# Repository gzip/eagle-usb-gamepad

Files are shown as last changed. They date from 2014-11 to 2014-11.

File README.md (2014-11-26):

# Classic Gamepad USB Adapter

This hardware and software allows you to connect your favorite classic gamepad to use as a joystick on your computer. The design is based on work from [raphnet.net](http://raphnet.net/electronique/electronique_en.php#1) and is completely open. The following configurations are supported:

- Four NES and/or SNES gamepads
- One N64 or Gamecube gamepad
- One Genesis or Atari gamepad

Connector footprints are also available for NES, SNES, and N64 under the [breakouts](./breakouts/) folder.

Gerbers

# Availability

Boards available at [OSH Park](https://www.oshpark.com/shared_projects/oCdHAtTx).

Kits available at [Tindie](https://www.tindie.com/products/gzip/classic-gamepad-usb-adapter/).

Photo of circuit

## License

All hardware and software is derivative of raphnet.net and is therefore GPL. The [breakout boards](./breakouts/) are original works and licensed under [Creative Commons Share Alike](http://creativecommons.org/licenses/by-sa/4.0/).

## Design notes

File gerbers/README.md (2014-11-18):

# Gerber Layers

| Layer Description | Extension |
| ---| ---|
| Bottom Copper | GBL |
| Bottom Solder Mask | GBS |
| Bottom Silk | GBO |
| Top Copper | GTL |
| Top Silk | GTO |
| Top Solder Mask | GTS |
| Outline | GML |
| Holes/Drills | TXT |

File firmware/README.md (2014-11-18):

# Firmware for the Classic Gamepad USB Adapter

The software here is provided by [raphnet.net](http://raphnet.net/electronique/electronique_en.php#1) and has been modified minimally to change the data pin(s), remove any code related to jumper settings, and change the VID/PID as requested by the original author. The following configurations are available here:

- Four NES and/or SNES gamepads
- One N64 or Gamecube gamepad
- One Genesis or Atari gamepad

## License

GPL

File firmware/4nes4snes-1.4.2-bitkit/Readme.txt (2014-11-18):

This is 4nes4snes Readme.txt file. 

Table of contents:

1) What is 4nes4snes?
2) USB Implementation
3) Compilation and installation
4) License
5) About the vendor id/product id pair:
6) Where do I get more information and updates?

1) What is 4nes4snes?
   --------------------
	4nes4snes if a firmware for Atmel ATmega8 and Atmega168* 
	which allows one to connect up to 4 NES and/or SNES 
	controllers to a PC using a single circuit. 

	The device connects to an USB port and appears to the
	PC as standard HID joystick with 4 report Id's. This means
	that it looks like 4 controllers in Windows's 
	control_panel->game_controllers window.

* Other devices from the same family are probably supported, but
not tested.

2) USB Implementation
   ------------------
	4nes4snes uses the software-only usb driver from Objective Development.
	See http://www.obdev.at/products/avrusb/index.html

	A good portion of 4nes4snes is based on Objective Development's
	HIDKeys example.

3) Compilation and installation
   ----------------------------
	First, you must compile it. To compile, you need a working avr-gcc and
	avr-libc. Under linux or cygwin, simply type make in the project directory.
	(assuming avr-gcc is in your path). 

	Next, you must upload the generated file (main.hex) to the Atmega8 using
	whatever tools you like. Personally, I use uisp. The 'flash' and 'fuse'
	targets in the makefile is a good example about how to use it. 

	The Atmega fuse bits must also be set properly. The idea behind this is to
	enable the external 12mhz crystal instead of the internal clock. Check the
	makefile for good fuse bytes values.

4) License
   -------
	4nes4snes is released under the GPLv2 license. See License.txt

5) About the vendor id/product id pair:
   ------------------------------------
	Please do not re-use them for other projects. Instead,
	obtain your own.

6) Where can I get more information and updates?
   --------------------------------------------
	Visit the 4nes4snes webpage:
	http://www.raphnet.net/electronique/4nes4snes/index_en.php
	you may also contact me by email:
	Raphael Assenat <raph@raphnet.net>

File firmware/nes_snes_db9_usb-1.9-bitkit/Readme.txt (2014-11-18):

This is nes_snes_db9_usb Readme.txt file. 

Table of contents:

1) What is nes_snes_db9_usb?
2) USB Implementation
3) Compilation and installation
4) License
5) About the vendor id/product id pair:
6) Where do I get more information and updates?

1) What is nes_snes_db9_usb?
   -------------------------
	nes_snes_db9_usb if a firmware for Atmel ATmega8 which 
	allows one to connect supported controllers to a PC via an USB
	port as a standard HID device.
	
	Supported controllers:
		- Nintendo Entertainment System (NES)
		- Famicon controller with built-in microphone
		- Super Nintendo Entertainment System (SNES)
		- Super Nintendo Mouse,
		- Genesis 3/6 buttons controllers
		- 2 Button atari-style controllers (such as Sega master system)
		- 1 Button atari-style controllers
		- Sega multi-tap MK-1654

2) USB Implementation
   ------------------
	nes_snes_db9_usb uses the software-only usb driver from Objective Development.
	See http://www.obdev.at/products/avrusb/index.html

	A good portion of the main.c code was based on Objective Development's
	HIDKeys example.

3) Compilation and installation
   ----------------------------
	First, you must compile it. To compile, you need a working avr-gcc and
	avr-libc. Under linux or cygwin, simply type make in the project directory.
	(assuming avr-gcc is in your path). 

	Next, you must upload the generated file (main.hex) to the Atmega8 using
	whatever tools you like. Personally, I use uisp. The 'flash' and 'fuse'
	targets in the makefile is a good example about how to use it. 

	The Atmega fuse bits must also be set properly. The idea behind this is to
	enable the external 12mhz crystal instead of the internal clock. Check the
	makefile for good fuse bytes values.

4) License
   -------
	nes_snes_db9_usb is released under Objective Development's extended GPL
	license. See License.txt

5) About the vendor id/product id pair:
   ------------------------------------
	Please dont re-use them for other projects. Instead, get your own. 
	I got mine from mecanique:
	http://www.mecanique.co.uk/products/usb/pid.html

6) Where do I get more information and updates?
   --------------------------------------------
	Visit my nes_snes_db9_usb page:
	http://www.raphnet.net/electronique/snes_nes_usb/index_en.php
	you may also contact me by email:
	Raphael Assenat <raph@raphnet.net>

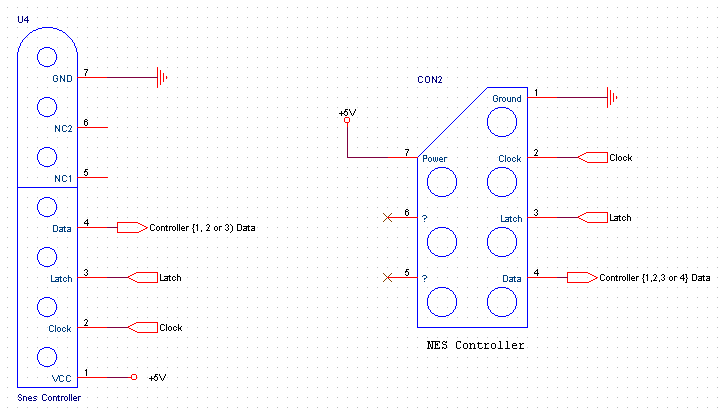
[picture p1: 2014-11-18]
firmware/4nes4snes-1.4.2-bitkit/circuit/sch-connectors.png

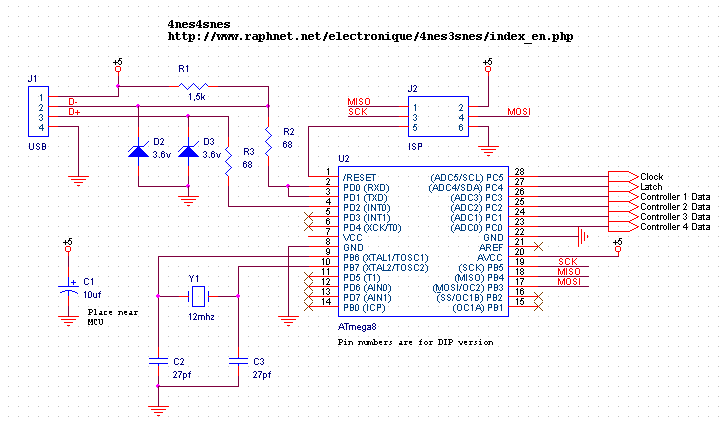
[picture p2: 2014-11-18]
firmware/4nes4snes-1.4.2-bitkit/circuit/sch-core.png

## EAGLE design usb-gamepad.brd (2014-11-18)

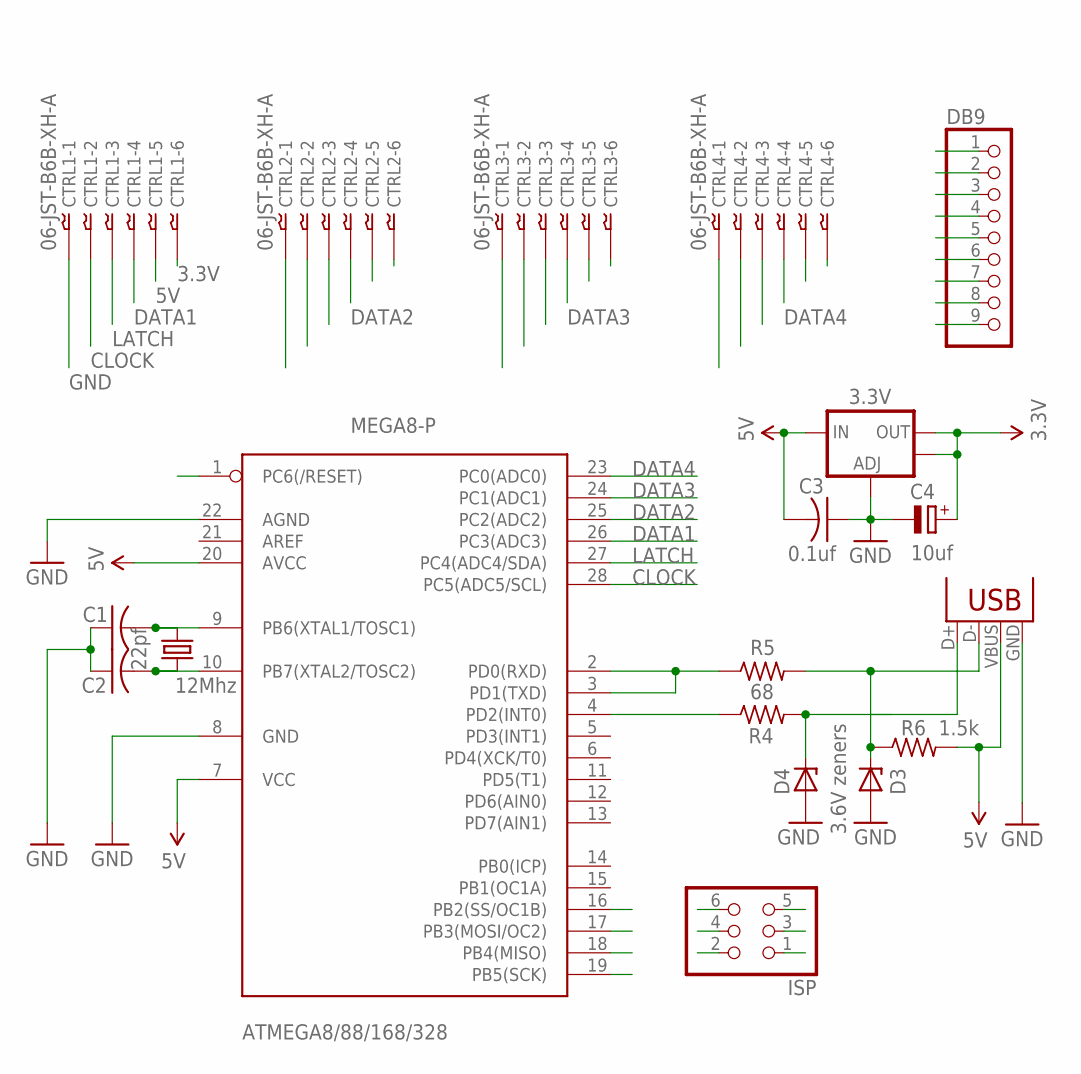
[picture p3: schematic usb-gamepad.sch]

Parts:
3.3V: V_REG_LM1117SOT223; SOT223
ATMEGA8/88/168/328: MEGA8-P; DIL28-3
C1, C2: 22pf; C025-025X050
C3: 0.1uf; C025-025X050
C4: 10uf; E2,5-5
CTRL1, CTRL2, CTRL3, CTRL4: 06-JST-B6B-XH-A; B6B-XH
D3: 3.6V zeners; DO41Z10
D4: 3.6V; DO41Z10
DB9: PINHD-1X9; 1X09
ISP: PINHD-2X3; 2X03
Q1: 12Mhz; HC49/S
R4, R5: 68; 0207/10
R6: 1.5k; 0207/10
USB: USBPTH; USB-B-PTH

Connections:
3.3V: 3.3V.2 (OUT), 3.3V.4 (OUT), C4.+, CTRL1.P$6, CTRL2.P$6, CTRL3.P$6, CTRL4.P$6
5V: 3.3V.3 (IN), ATMEGA8/88/168/328.7 (VCC), ATMEGA8/88/168/328.20 (AVCC), C3.2, CTRL1.P$5, CTRL2.P$5, CTRL3.P$5, CTRL4.P$5, DB9.5, ISP.2, R6.2, USB.VBUS
CLOCK: ATMEGA8/88/168/328.28 (PC5(ADC5/SCL)), CTRL1.P$2, CTRL2.P$2, CTRL3.P$2, CTRL4.P$2, DB9.1
D+: D4.C, R4.2, USB.D+
D-: D3.C, R5.2, R6.1, USB.D-
DATA1: ATMEGA8/88/168/328.26 (PC3(ADC3)), CTRL1.P$4, DB9.3
DATA2: ATMEGA8/88/168/328.25 (PC2(ADC2)), CTRL2.P$4, DB9.4
DATA3: ATMEGA8/88/168/328.24 (PC1(ADC1)), CTRL3.P$4, DB9.6
DATA4: ATMEGA8/88/168/328.23 (PC0(ADC0)), CTRL4.P$4, DB9.7
GND: 3.3V.1 (ADJ), ATMEGA8/88/168/328.8 (GND), ATMEGA8/88/168/328.22 (AGND), C1.1, C2.1, C3.1, C4.-, CTRL1.P$1, CTRL2.P$1, CTRL3.P$1, CTRL4.P$1, D3.A, D4.A, DB9.8, ISP.6, USB.GND
LATCH: ATMEGA8/88/168/328.27 (PC4(ADC4/SDA)), CTRL1.P$3, CTRL2.P$3, CTRL3.P$3, CTRL4.P$3, DB9.2
MISO: ATMEGA8/88/168/328.18 (PB4(MISO)), ISP.1
MOSI: ATMEGA8/88/168/328.17 (PB3(MOSI/OC2)), ISP.4
unnamed: ATMEGA8/88/168/328.10 (PB7(XTAL2/TOSC2)), C2.2, Q1.1
unnamed: ATMEGA8/88/168/328.9 (PB6(XTAL1/TOSC1)), C1.2, Q1.2
unnamed: ATMEGA8/88/168/328.2 (PD0(RXD)), ATMEGA8/88/168/328.3 (PD1(TXD)), R5.1
unnamed: ATMEGA8/88/168/328.4 (PD2(INT0)), R4.1
RESET: ATMEGA8/88/168/328.1 (PC6(/RESET)), ISP.5
SCK: ATMEGA8/88/168/328.19 (PB5(SCK)), DB9.9, ISP.3
SS: ATMEGA8/88/168/328.16 (PB2(SS/OC1B))

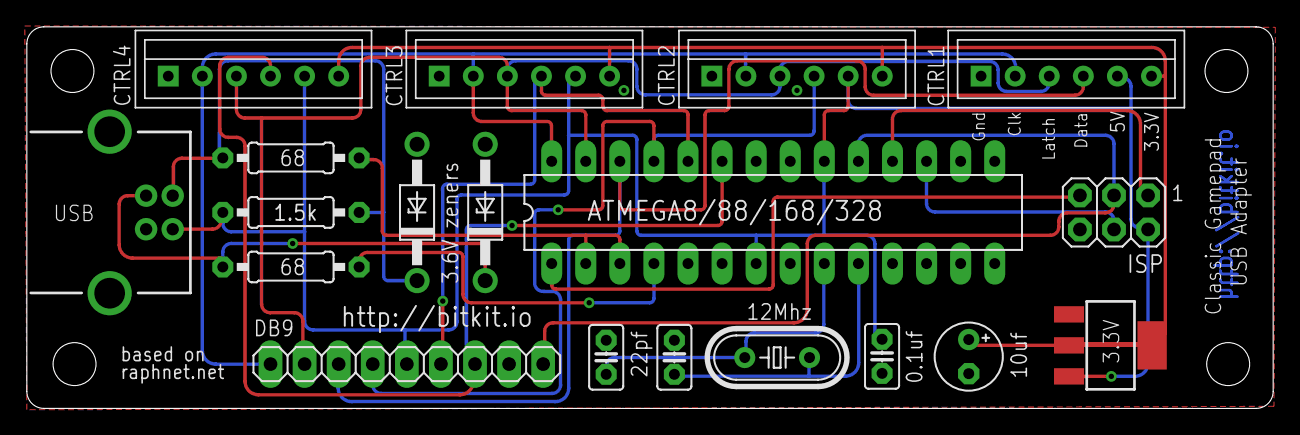
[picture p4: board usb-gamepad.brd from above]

Board: 2 copper layers, 92.9 x 28.4 mm, 19 parts (0 on the bottom side), 19 nets.

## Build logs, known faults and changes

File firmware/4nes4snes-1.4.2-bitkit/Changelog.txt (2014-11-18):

--- v1.4.2 (July 14, 2013)
- Corrected the USB Vendor ID

--- v1.4.1 (April 26, 2013)
- Reduced declared max current from 120mA to 100mA. This makes
it possible to connect the adapter to my keyboard USB port but
is still a conservative estimate for the worst combination
of hypothetical non-standard power hungry controllers.
- Some code cleanups

--- v1.4 (April 20, 2013)
- Support for Atmega168. Use Makefile.atmega168.
- New USB VID/PID
- Simplified main loop by remving setIdle/getIdle implementation. Optional for
  joysticks according to HID specification appendix G.

--- v1.3 (April 2012)
- Added support for SNES multitaps in 4 player mode.

--- v1.2 (May 2, 2009)
- License changed to GPLv2
- Implemented "Live autodetection". This allows NES and SNES controllers to be
changed at runtime. This feature can be disabled by closing JP1.
- Added NES fourscore support. When a fourscore is detected in port 1, fourscore
mode is entered and ports 1 and 2 are used to read up to 4 NES controllers.

--- v1.1 (18 Apr 2007)
- Changed report descriptor. There are now four separate report IDs, one
per controller. This was necessary because even though all axis and buttons
were perfectly functional in 'control panel -> game controllers', it was not
the case in many games, including zsnes and snes9x!
- Changed device id to 0x0A9D

--- v1.0 (24 Mar 2007)
Initial release.

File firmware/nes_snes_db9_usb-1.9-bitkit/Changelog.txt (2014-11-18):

--- v1.9 (Nov 16, 2011)
   - Special features added to support the Famicom controller with
     microphone. Wire the 'jumpers' in NES mode and short PC0 and PC1
	 together to enable this new mode.

     For reference, the famicom controller I used had the following color code:
	   Red: GND
	   Blue: VCC
	   Brown: Microphone out
	   White: Clock
	   Yellow: Latch
       Orange: Data out

	 Wire the extra input (PC2) for the microphone digital signal from the controller.

     In an attempt to compensate for the lack of start and select buttons,
	 the following 3 Buttons mappings have been implemented:

	 Configuration 1 (just connect the controller)
       Button A -> USB Button 1
       Button B -> USB Button 2
       Button A+B -> USB Button 3 (and buttons 1 & 2)
       Microphone -> USB Button 4

     Configuration 2 (connect adapter while holding A)
	   Microphone -> USB Button 1
	   Button B -> USB Button 2
	   Button A + B -> USB Button 3 (buttons 2 and 4 off)
       Button A -> USB Button 4

     Configuration 3 (connect adapter while holding B)
	   Button A -> USB Button 1
	   Microphone -> USB Button 2
	   Button A + B -> USB Button 3 (buttons 2 and 4 off)
	   Button B -> USB Button 4

   - Fixed the device name. (It would be corrupted or would not appear)

--- v1.8 (Jul 11, 2011)
	- TGFX has its own device name and VID/PID
	- Sega Paddle support (HPD-200). Auto-detected in DB9 mode.
		This controller has only one button. But if you install 
		the circuit inside the controller, you can rewire
		a button to PB4 to get an extra button (BTN2). 
		The "not rewired" button will be BTN1.

		A few modes of operation are available and selected
		by holding buttons when connecting the adapter:

	    Mode 1 (default) : Paddle left-right, 1 button.
		Mode 2 (hold btn1) : Paddle up-down, 1 button.
		Mode 3 (hold btn2) : Paddle left-right, 2 buttons.
		Mode 4 (hold btn1 + btn2) : Paddle Up-down, 2 buttons.
    - Controller polling synchronized with USB polls. Helps maintain
	  an accurate timing when polling the controllers.

--- v1.7 (Sep 13, 2008)
   - TGFX Support
   - Improved Genesis 6 Button auto-detection
   - Mode button now usable with Genesis 6 Button controllers
   - Sega style Multitap support (tested with MK-1654 only!)

--- v1.6 (Dec 12, 2007)
   - Changed the button IDs. Atari and SMS controllers were
     using button 2 and 3. Some emulators require button 1 so....
   - Added a way to force 6 Button mode for genesis controllers. Just
     in case your 6 button controller is not detected. Hold 'start' when connecting
	 the USB cable to use this feature.

--- v1.5 (Nov 10, 2007)
	- Added support for Genesis 3 and 6 button controllers.
	- All DB9 controllers (Genesis 3/6, SMS, Atari style 1 or 2 button and
	compatible) are auto-detected.
	- The wiring is now different for Atari style controllers. Easier to wire
	to the multiuse PCB.
	- NES controllers are now detected in SNES mode. This works great with
	original Nintendo controllers. If you have trouble with clones, use
	NES-only mode.
	- The project is now released under the GPL v2 license.

--- v1.4 (Dec 3, 2006)
	- Added support for Atari style joysticks. Two button
	  variations (SMS) are supported.
	- Added padding to nes report descriptor. This makes it
	  work correcly on windows. Linux sure is tolerant...

--- v1.3 (Oct 28, 2006)
	- Fixed a bug in nes.c, snes.c and snesmouse.c which prevented the pullup
		on the data pin (from device) from being enabled. This resulted in
		random button toggling when no controller was connected.
	- A separate USB PID is used when in NES mode.
	- PD1 is now left as input (no pullup) since it is shorted with PD0 on the
	  PCB rev.C. (And I didnt want to scrap a batch of 50 pcb nor cut a track
	  and solder a wire 50 times...)

--- v1.2 (Oct 6, 2006)
Added serial number
Added support for Snes mouse (auto detected in snes mode)
	- Default speed: Low
	- 3 Speeds selectable by holding some buttons at
	  startup (USB connect or mouse connect)
	  Left+right buttons: Low speed
	  Left buton: Medium speed
	  Right button: High speed
	  No button: Default speed when USB connect,
	  			continue using same speed for mouse (re)-connect

--- v1.1
Reworked report descriptor for better behaviour 
in Windows and Mac OS X

--- v1.0 (Jul 5, 2006)
Initial release:
Snes gamepad support
Nes gamepad support

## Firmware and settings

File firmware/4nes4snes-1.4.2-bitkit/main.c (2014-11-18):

/* Name: main.c
 * Project: Multiple NES/SNES to USB converter
 * Author: Raphael Assenat <raph@raphnet.net>
 * Copyright: (C) 2007-2009 Raphael Assenat <raph@raphnet.net>
 * License: GPLv2
 * Tabsize: 4
 * Comments: Based on HID-Test by Christian Starkjohann
 */
#include <avr/io.h>
#include <avr/interrupt.h>
#include <avr/pgmspace.h>
#include <avr/wdt.h>
#include <util/delay.h>
#include <string.h>

#include "usbdrv.h"
#include "gamepad.h"

#include "fournsnes.h"

#include "devdesc.h"

static uchar *rt_usbHidReportDescriptor=NULL;
static uchar rt_usbHidReportDescriptorSize=0;
static uchar *rt_usbDeviceDescriptor=NULL;
static uchar rt_usbDeviceDescriptorSize=0;


#if defined(__AVR_ATmega168__) || defined(__AVR_ATmega168A__) || \
	defined(__AVR_ATmega168P__) || defined(__AVR_ATmega328__) || \
	defined(__AVR_ATmega328P__) || defined(__AVR_ATmega88__) || \
	defined(__AVR_ATmega88A__) || defined(__AVR_ATmega88P__) || \
	defined(__AVR_ATmega88PA__)
#define AT168_COMPATIBLE
#endif

/* The maximum number of independent reports that are supported. */
#define MAX_REPORTS 8	

PROGMEM const int usbDescriptorStringSerialNumber[]  = {
	USB_STRING_DESCRIPTOR_HEADER(4),
	'1','0','0','0'
};

int usbDescriptorStringDevice[] = {
	USB_STRING_DESCRIPTOR_HEADER(DEVICE_STRING_LENGTH),
	DEFAULT_PROD_STRING
};

const char usbDescriptorConfiguration[] = { 0 }; // dummy

uchar my_usbDescriptorConfiguration[] = {    /* USB configuration descriptor */
    9,          /* sizeof(usbDescriptorConfiguration): length of descriptor in bytes */
    USBDESCR_CONFIG,    /* descriptor type */
    18 + 7 * USB_CFG_HAVE_INTRIN_ENDPOINT + 9, 0,
                /* total length of data returned (including inlined descriptors) */
    1,          /* number of interfaces in this configuration */
    1,          /* index of this configuration */
    0,          /* configuration name string index */
#if USB_CFG_IS_SELF_POWERED
    USBATTR_SELFPOWER,  /* attributes */
#else
    USBATTR_BUSPOWER,   /* attributes */
#endif
    USB_CFG_MAX_BUS_POWER/2,            /* max USB current in 2mA units */
/* interface descriptor follows inline: */
    9,          /* sizeof(usbDescrInterface): length of descriptor in bytes */
    USBDESCR_INTERFACE, /* descriptor type */
    0,          /* index of this interface */
    0,          /* alternate setting for this interface */
    USB_CFG_HAVE_INTRIN_ENDPOINT,   /* endpoints excl 0: number of endpoint descriptors to follow */
    USB_CFG_INTERFACE_CLASS,
    USB_CFG_INTERFACE_SUBCLASS,
    USB_CFG_INTERFACE_PROTOCOL,
    0,          /* string index for interface */
//#if (USB_CFG_DESCR_PROPS_HID & 0xff)    /* HID descriptor */
    9,          /* sizeof(usbDescrHID): length of descriptor in bytes */
    USBDESCR_HID,   /* descriptor type: HID */
    0x01, 0x01, /* BCD representation of HID version */
    0x00,       /* target country code */
    0x01,       /* number of HID Report (or other HID class) Descriptor infos to follow */
    0x22,       /* descriptor type: report */
    USB_CFG_HID_REPORT_DESCRIPTOR_LENGTH, 0,  /* total length of report descriptor */
//#endif
#if USB_CFG_HAVE_INTRIN_ENDPOINT    /* endpoint descriptor for endpoint 1 */
    7,          /* sizeof(usbDescrEndpoint) */
    USBDESCR_ENDPOINT,  /* descriptor type = endpoint */
    0x81,       /* IN endpoint number 1 */
    0x03,       /* attrib: Interrupt endpoint */
    8, 0,       /* maximum packet size */
    USB_CFG_INTR_POLL_INTERVAL, /* in ms */
#endif
};


static Gamepad *curGamepad;


/* ----------------------- hardware I/O abstraction ------------------------ */

static void hardwareInit(void)
{

	/* PORTB
	 * 
	 * Bit     Description       Direction    Level/pu 
	 * 0       Jumpers common    Out          0
	 * 1       JP1               In           1
	 * 2       JP2               In           1
	 * 3       MOSI              In           1
	 * 4       MISO              In           1
	 * 5       SCK               In           1
	 * 6       -
	 * 7       -
	 */
	DDRB = 0x01;
	PORTB = 0xFE;

	// init port C as input with pullup
	DDRC = 0x00;
	PORTC = 0xff;

	/*
	 * For port D, activate pull-ups on all lines except the D+, D- and bit 1.
	 *
	 * For historical reasons (a mistake on an old PCB), bit 1
	 * is now always connected with bit 0. So bit 1 configured
	 * as an input without pullup.
	 *
	 * Usb pin are init as output, low. (device reset). They are released
	 * later when usbReset() is called.
	 */
	PORTD = 0xf8;
	DDRD = 0x01 | 0x04;    

	/* Configure timers */	
#if defined(AT168_COMPATIBLE)
	TCCR2A= (1<<WGM21);
	TCCR2B=(1<<CS22)|(1<<CS21)|(1<<CS20);
	OCR2A=196;  // for 60 hz
#else	
	TCCR2 = (1<<WGM21)|(1<<CS22)|(1<<CS21)|(1<<CS20);
	OCR2 = 196; // for 60 hz
#endif
}

static void usbReset(void)
{
	/* [...] a single ended zero or SE0 can be used to signify a device 
	   reset if held for more than 10mS. A SE0 is generated by holding 
       both th D- and D+ low (< 0.3V). 
	*/
	
	PORTD &= ~(0x01 | 0x04); // Set D+ and D- to 0
	DDRD |= 0x01 | 0x04;    
	_delay_ms(15);
	DDRD &= ~(0x01 | 0x04);
}

#if defined(AT168_COMPATIBLE)

#define mustPollControllers()	(TIFR2 & (1<<OCF2A))
#define clrPollControllers()	do { TIFR2 = 1<<OCF2A; } while(0)

#else

#define mustPollControllers()	(TIFR & (1<<OCF2))
#define clrPollControllers()	do { TIFR = 1<<OCF2; } while(0)

#endif


static uchar    reportBuffer[12];    /* buffer for HID reports */



/* ------------------------------------------------------------------------- */
/* ----------------------------- USB interface ----------------------------- */
/* ------------------------------------------------------------------------- */

uchar	usbFunctionDescriptor(struct usbRequest *rq)
{
	if ((rq->bmRequestType & USBRQ_TYPE_MASK) != USBRQ_TYPE_STANDARD)
		return 0;

	if (rq->bRequest == USBRQ_GET_DESCRIPTOR)
	{
		// USB spec 9.4.3, high byte is descriptor type
		switch (rq->wValue.bytes[1])
		{
			case USBDESCR_DEVICE:
				usbMsgPtr = rt_usbDeviceDescriptor;		
				return rt_usbDeviceDescriptorSize;
			case USBDESCR_HID_REPORT:
				usbMsgPtr = rt_usbHidReportDescriptor;
				return rt_usbHidReportDescriptorSize;
			case USBDESCR_CONFIG:
				usbMsgPtr = my_usbDescriptorConfiguration;
				return sizeof(my_usbDescriptorConfiguration);
		}
	}

	return 0;
}


static uchar reportPos=0;

uchar	usbFunctionSetup(uchar data[8])
{
	usbRequest_t    *rq = (void *)data;

	usbMsgPtr = reportBuffer;

	/* class request type */
	if((rq->bmRequestType & USBRQ_TYPE_MASK) == USBRQ_TYPE_CLASS){    
		switch (rq->bRequest)
		{
			case USBRQ_HID_GET_REPORT:
				/* wValue: ReportType (highbyte), ReportID (lowbyte) */
				reportPos=0;
				return curGamepad->buildReport(reportBuffer, rq->wValue.bytes[0]);
			
		}
	} else {
		/* no vendor specific requests implemented */
	}
	return 0;
}

/* ------------------------------------------------------------------------- */

int main(void)
{
	char must_report = 0;	/* bitfield */
	int i;
	unsigned char run_mode;


	hardwareInit();	

	_delay_ms(10); /* let pins settle */
	run_mode = (PINB & 0x06)>>1;

	switch(run_mode)
	{
			// Close JP1 to disable live auto-detect
		case 2:
			disableLiveAutodetect();
			break;

		case 1:
		case 3:
		case 4:
			break;
	}

	curGamepad = fournsnesGetGamepad();

	// configure report descriptor according to
	// the current gamepad
	rt_usbHidReportDescriptor = curGamepad->reportDescriptor;
	rt_usbHidReportDescriptorSize = curGamepad->reportDescriptorSize;

	if (curGamepad->deviceDescriptor != 0)
	{
		rt_usbDeviceDescriptor = (void*)curGamepad->deviceDescriptor;
		rt_usbDeviceDescriptorSize = curGamepad->deviceDescriptorSize;
	}
	else
	{
		// use descriptor from devdesc.c
		//
		rt_usbDeviceDescriptor = (void*)usbDescrDevice;
		rt_usbDeviceDescriptorSize = getUsbDescrDevice_size();
	}

	// patch the config descriptor with the HID report descriptor size
	my_usbDescriptorConfiguration[25] = rt_usbHidReportDescriptorSize;

	usbReset();
	curGamepad->init();
	usbInit();

	curGamepad->update();

	sei();
	
	for(;;){	/* main event loop */
		wdt_reset();

		// this must be called at each 50 ms or less
		usbPoll();

		/* Read the controllers at 60hz */
		if (mustPollControllers())
		{
			clrPollControllers();
		
			curGamepad->update();

			/* Check what will have to be reported */
			for (i=0; i<curGamepad->num_reports; i++) {
				if (curGamepad->changed(i+1)) {
					must_report |= (1<<i);
				}
			}
		}

			
		if(must_report)
		{
			for (i = 0; i < curGamepad->num_reports; i++)
			{
				if ((must_report & (1<<i)) == 0) 
					continue;

				if (usbInterruptIsReady())
				{ 	
					char len;

					len = curGamepad->buildReport(reportBuffer, i+1);
					usbSetInterrupt(reportBuffer, len);

					while (!usbInterruptIsReady())
					{
						usbPoll();
						wdt_reset();
					}
				}
			}

			must_report = 0;
		}
	}
	return 0;
}

/* ------------------------------------------------------------------------- */

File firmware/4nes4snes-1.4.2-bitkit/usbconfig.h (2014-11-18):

/* Name: usbconfig.h
 * Project: AVR USB driver
 * Author: Christian Starkjohann
 * Creation Date: 2005-04-01
 * Tabsize: 4
 * Copyright: (c) 2005 by OBJECTIVE DEVELOPMENT Software GmbH
 * License: GNU GPL v2 (see License.txt) or proprietary (CommercialLicense.txt)
 * This Revision: $Id: usbconfig.h,v 1.12 2013-07-14 04:30:45 cvs Exp $
 */

#ifndef __usbconfig_h_included__
#define __usbconfig_h_included__

/*
General Description:
This file is an example configuration (with inline documentation) for the USB
driver. It configures AVR-USB for an ATMega8 with USB D+ connected to Port D
bit 2 (which is also hardware interrupt 0) and USB D- to Port D bit 0. You may
wire the lines to any other port, as long as D+ is also wired to INT0.
To create your own usbconfig.h file, copy this file to the directory
containing "usbdrv" (that is your project firmware source directory) and
rename it to "usbconfig.h". Then edit it accordingly.
*/

/* ---------------------------- Hardware Config ---------------------------- */

#define USB_CFG_IOPORTNAME      D
/* This is the port where the USB bus is connected. When you configure it to
 * "B", the registers PORTB, PINB and DDRB will be used.
 */
#define USB_CFG_DMINUS_BIT      0
/* This is the bit number in USB_CFG_IOPORT where the USB D- line is connected.
 * This may be any bit in the port.
 */
#define USB_CFG_DPLUS_BIT       2
/* This is the bit number in USB_CFG_IOPORT where the USB D+ line is connected.
 * This may be any bit in the port. Please note that D+ must also be connected
 * to interrupt pin INT0!
 */
#define USB_CFG_CLOCK_KHZ       (F_CPU/1000)
/* Clock rate of the AVR in MHz. Legal values are 12000, 15000, 16000 or 16500.
 * The 16.5 MHz version of the code requires no crystal, it tolerates +/- 1%
 * deviation from the nominal frequency. All other rates require a precision
 * of 2000 ppm and thus a crystal!
 * Default if not specified: 12 MHz
 */

/* ----------------------- Optional Hardware Config ------------------------ */

/* #define USB_CFG_PULLUP_IOPORTNAME   D */
/* If you connect the 1.5k pullup resistor from D- to a port pin instead of
 * V+, you can connect and disconnect the device from firmware by calling
 * the macros usbDeviceConnect() and usbDeviceDisconnect() (see usbdrv.h).
 * This constant defines the port on which the pullup resistor is connected.
 */
/* #define USB_CFG_PULLUP_BIT          4 */
/* This constant defines the bit number in USB_CFG_PULLUP_IOPORT (defined
 * above) where the 1.5k pullup resistor is connected. See description
 * above for details.
 */

/* --------------------------- Functional Range ---------------------------- */
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

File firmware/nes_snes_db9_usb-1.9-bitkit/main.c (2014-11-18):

/* Nes/Snes/Genesis/SMS/Atari to USB
 * Copyright (C) 2006-2011 Raphaël Assénat
 *
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
 * The author may be contacted at raph@raphnet.net
 */
#include <avr/io.h>
#include <avr/interrupt.h>
#include <avr/pgmspace.h>
#include <avr/sleep.h>
#include <avr/wdt.h>
#include <util/delay.h>
#include <string.h>

#include "usbdrv.h"
#include "oddebug.h"
#include "gamepad.h"

#include "snes.h"
#include "snesmouse.h"
#include "nes.h"
#include "db9.h"
#include "tg16.h"
#include "segamtap.h"

#include "leds.h"
#include "devdesc.h"

static uchar *rt_usbHidReportDescriptor=NULL;
static uchar rt_usbHidReportDescriptorSize=0;
static uchar *rt_usbDeviceDescriptor=NULL;
static uchar rt_usbDeviceDescriptorSize=0;

#define MAX_REPORTS	8

PROGMEM const int usbDescriptorStringSerialNumber[]  = {
 	USB_STRING_DESCRIPTOR_HEADER(4),
	'1','0','0','0'
};

int usbDescriptorStringDevice[] = {
 	USB_STRING_DESCRIPTOR_HEADER(DEVICE_STRING_LENGTH),
	DEFAULT_PROD_STRING
};

char usbDescriptorConfiguration[] = { 0 }; // dummy

uchar my_usbDescriptorConfiguration[] = {    /* USB configuration descriptor */
    9,          /* sizeof(usbDescriptorConfiguration): length of descriptor in bytes */
    USBDESCR_CONFIG,    /* descriptor type */
    18 + 7 * USB_CFG_HAVE_INTRIN_ENDPOINT + 9, 0,
                /* total length of data returned (including inlined descriptors) */
    1,          /* number of interfaces in this configuration */
    1,          /* index of this configuration */
    0,          /* configuration name string index */
#if USB_CFG_IS_SELF_POWERED
    USBATTR_SELFPOWER,  /* attributes */
#else
    USBATTR_BUSPOWER,   /* attributes */
#endif
    USB_CFG_MAX_BUS_POWER/2,            /* max USB current in 2mA units */
/* interface descriptor follows inline: */
    9,          /* sizeof(usbDescrInterface): length of descriptor in bytes */
    USBDESCR_INTERFACE, /* descriptor type */
    0,          /* index of this interface */
    0,          /* alternate setting for this interface */
    USB_CFG_HAVE_INTRIN_ENDPOINT,   /* endpoints excl 0: number of endpoint descriptors to follow */
    USB_CFG_INTERFACE_CLASS,
    USB_CFG_INTERFACE_SUBCLASS,
    USB_CFG_INTERFACE_PROTOCOL,
    0,          /* string index for interface */
//#if (USB_CFG_DESCR_PROPS_HID & 0xff)    /* HID descriptor */
    9,          /* sizeof(usbDescrHID): length of descriptor in bytes */
    USBDESCR_HID,   /* descriptor type: HID */
    0x01, 0x01, /* BCD representation of HID version */
    0x00,       /* target country code */
    0x01,       /* number of HID Report (or other HID class) Descriptor infos to follow */
    0x22,       /* descriptor type: report */
    USB_CFG_HID_REPORT_DESCRIPTOR_LENGTH, 0,  /* total length of report descriptor */
//#endif
#if USB_CFG_HAVE_INTRIN_ENDPOINT    /* endpoint descriptor for endpoint 1 */
    7,          /* sizeof(usbDescrEndpoint) */
    USBDESCR_ENDPOINT,  /* descriptor type = endpoint */
    0x81,       /* IN endpoint number 1 */
    0x03,       /* attrib: Interrupt endpoint */
    8, 0,       /* maximum packet size */
    USB_CFG_INTR_POLL_INTERVAL, /* in ms */
#endif
};

static Gamepad *curGamepad;


/* ----------------------- hardware I/O abstraction ------------------------ */

static void hardwareInit(void)
{
	uchar	i, j;

	// init port C as input with pullup
	DDRC = 0x00;
	PORTC = 0xff;
	
	/* 1101 1000 bin: activate pull-ups except on USB lines 
	 *
	 * USB signals are on bit 0 and 2. 
	 *
	 * Bit 1 is connected with bit 0 (rev.C pcb error), so the pullup
	 * is not enabled.
	 * */
	PORTD = 0xf8;   

	/* Usb pin are init as outputs */
	DDRD = 0x01 | 0x04;    

	
	j = 0;
	while(--j){     /* USB Reset by device only required on Watchdog Reset */
		i = 0;
		while(--i); /* delay >10ms for USB reset */
	}
	DDRD = 0x00;    /* 0000 0000 bin: remove USB reset condition */
			/* configure timer 0 for a rate of 12M/(1024 * 256) = 45.78 Hz (~22ms) */
	TCCR0 = 5;      /* timer 0 prescaler: 1024 */

	TCCR2 = (1<<WGM21)|(1<<CS22)|(1<<CS21)|(1<<CS20);
	OCR2 = 196; // for 60 hz

}

static uchar    reportBuffer[6];    /* buffer for HID reports */



/* ------------------------------------------------------------------------- */
/* ----------------------------- USB interface ----------------------------- */
/* ------------------------------------------------------------------------- */

static uchar    idleRates[MAX_REPORTS];           /* in 4 ms units */

uchar	usbFunctionDescriptor(struct usbRequest *rq)
{
	if ((rq->bmRequestType & USBRQ_TYPE_MASK) != USBRQ_TYPE_STANDARD)
		return 0;

	if (rq->bRequest == USBRQ_GET_DESCRIPTOR)
	{
		// USB spec 9.4.3, high byte is descriptor type
		switch (rq->wValue.bytes[1])
		{
			case USBDESCR_DEVICE:
				usbMsgPtr = rt_usbDeviceDescriptor;		
				return rt_usbDeviceDescriptorSize;
			case USBDESCR_HID_REPORT:
				usbMsgPtr = rt_usbHidReportDescriptor;
				return rt_usbHidReportDescriptorSize;
			case USBDESCR_CONFIG:
				usbMsgPtr = my_usbDescriptorConfiguration;
				return sizeof(my_usbDescriptorConfiguration);
		}
	}

	return 0;
}

static uchar setupBuffer[sizeof(reportBuffer)];

uchar	usbFunctionSetup(uchar data[8])
{
	usbRequest_t    *rq = (void *)data;
	int i;

	usbMsgPtr = setupBuffer;
	if((rq->bmRequestType & USBRQ_TYPE_MASK) == USBRQ_TYPE_CLASS){    /* class request type */

		switch (rq->bRequest)
		{
			case USBRQ_HID_GET_REPORT:
				/* wValue: ReportType (highbyte), ReportID (lowbyte) */
				return curGamepad->buildReport(setupBuffer, rq->wValue.bytes[0]);

			case USBRQ_HID_GET_IDLE:
				if (rq->wValue.bytes[0] > 0 && rq->wValue.bytes[0] <= MAX_REPORTS) {
					usbMsgPtr = idleRates + (rq->wValue.bytes[0] - 1);
					return 1;
				}
				break;

			case USBRQ_HID_SET_IDLE:
				if (rq->wValue.bytes[0]==0) {
					for (i=0; i<MAX_REPORTS; i++)
						idleRates[i] = rq->wValue.bytes[1];
				}
				else {
					if (rq->wValue.bytes[0] > 0 && rq->wValue.bytes[0] <= MAX_REPORTS) {
						idleRates[rq->wValue.bytes[0]-1] = rq->wValue.bytes[1];
					}
				}
				break;
		}
	}else{
	/* no vendor specific requests implemented */
	}
	return 0;
}
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

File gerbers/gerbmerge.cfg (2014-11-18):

[DEFAULT]
projdir = .

MergeOut = panel
ProjName = usb-gamepad

[Options]

#CropMarkLayers = *topsilkscreen,*bottomsilkscreen

# Set the maximum dimensions of the final panel, if known. You can set the
# dimensions of the maximum panel size supported by your board manufacturer,
# and GerbMerge will print an error message if your layout exceeds these
# dimensions. Alternatively, when using automatic placement, the panel sizes
# listed here constrain the random placements such that only placements that
# fit within the given panel dimensions will be considered. The dimensions are
# specified in inches.
# 10cm = 3.93701in
# 5cm = 1.9685in

PanelWidth = 3.93701
PanelHeight = 3.93701

# Set the amount of extra space to leave around the edges of the panel to
# simplify tooling and handling. These margins are specified in inches, and
# default to 0" if not specified. These spacings will only be visible to the
# board manufacturer if you enable crop marks (see CropMarkLayers above) or use
# an OutlineLayer.
LeftMargin   = 0.1
RightMargin  = 0.1
TopMargin    = 0.1
BottomMargin = 0.1

# Set the inter-job spacing (inches) in both the X-dimension (width) and
# Y-dimension (height). Normally these would be the same unless you're trying
# really hard to make your jobs fit into a panel of exact size and you need to
# tweak these spacings to make it work. 0.125" is probably generous, about half
# that is practical for using a band saw, but you probably want to leave it at
# 0.125" if you have copper features close to the board edges and/or are using
# less precise tools, like a hacksaw, for separating the boards.
# 1mm = 0.0393701
XSpacing = 0.0393701
YSpacing = 0.0393701

# Width of cut lines, in inches. The default value is 0.01". These are drawn on
# the layers specified by CutLineLayers.
CutLineWidth = 0.01

# Width of crop marks, in inches. The default value is 0.01". These are drawn on
# the layers specified by CropMarkLayers.
CropMarkWidth = 0.01

# This option is intended to reduce the probability of forgetting to include a
# layer in a job description when panelizing two or more different jobs.
# Unless this option is set to 1, an error will be raised if some jobs do not
# have the same layer names as the others, i.e., are missing layers. For
# example, if one job has a top-side soldermask layer and another doesn't, that
# could be a mistake. Setting this option to 1 prevents this situation from
# raising an error.
AllowMissingLayers = 1

# This option is intended to reduce the number of drills in the output by
# eliminating drill sizes that are too close to make a difference. For example,
# it probably does not make sense to have two separate 0.031" and 0.0315"
# drills. The DrillClusterTolerance value specifies how much tolerance is
# allowed in drill sizes, in units of inches. Multiple drill tools that span
# twice this tolerance will be clustered into a single drill tool. For example,
# a set of 0.031", 0.0315", 0.032", and 0.034" drills will all be replaced by a
# single drill tool of diameter (0.031"+0.034")/2 = 0.0325". It is guaranteed
# that all original drill sizes will be no farther than DrillClusterTolerance
# from the drill tool size generated by clustering.
#
# Setting DrillClusterTolerance to 0 disables clustering.
DrillClusterTolerance = 0.002

# Use this option to automatically thicken features on particular layers. This
# is intended for thickening silkscreen to some minimum width. The value of
# this option must be a comma-separated list of layer names followed by minimum
# feature sizes (in inches) for that layer. Comment this out to disable thickening.
#MinimumFeatureSize = *topsilkscreen,0.008,*bottomsilkscreen,0.008

[MergeOutputFiles]
Prefix = %(projname)s_%(mergeout)s

*TopLayer=%(prefix)s.GTL
*BottomLayer=%(prefix)s.GBL
*TopSilkscreen=%(prefix)s.GTO
*BottomSilkscreen=%(prefix)s.GBO
*TopSoldermask=%(prefix)s.GTS
*BottomSoldermask=%(prefix)s.GBS
Drills=%(prefix)s.TXT
BoardOutline=%(prefix)s.GML
ToolList = %(prefix)s.toollist.drl
Placement = %(prefix)s.placement.plc

[Proj]

Prefix=%(projdir)s/%(projname)s

*TopLayer=%(prefix)s.GTL
*BottomLayer=%(prefix)s.GBL
*TopSilkscreen=%(prefix)s.GTO
*BottomSilkscreen=%(prefix)s.GBO
*TopSoldermask=%(prefix)s.GTS
*BottomSoldermask=%(prefix)s.GBS
Drills=%(prefix)s.TXT
BoardOutline=%(prefix)s.GML

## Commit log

2014-11-18 Add gerbers folder
    [gerbmerge.cfg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]
2014-11-18 Add gerbers readme

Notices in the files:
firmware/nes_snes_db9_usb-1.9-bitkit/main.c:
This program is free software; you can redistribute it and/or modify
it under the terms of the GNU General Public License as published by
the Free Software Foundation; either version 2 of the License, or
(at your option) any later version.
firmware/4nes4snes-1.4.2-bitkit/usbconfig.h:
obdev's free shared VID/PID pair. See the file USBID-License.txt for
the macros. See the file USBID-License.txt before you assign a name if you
